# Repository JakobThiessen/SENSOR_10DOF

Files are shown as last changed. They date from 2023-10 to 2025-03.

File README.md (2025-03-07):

# SENSOR_10DOF

- ACC/Gyro	(BMI160/323)
- ACC/Mag	(LSM303AGR)
- T/P/RH	(BME280)

# Hardware

<p float="left">
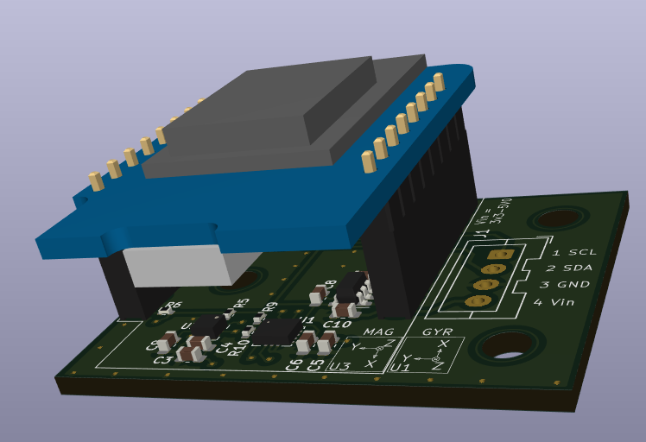
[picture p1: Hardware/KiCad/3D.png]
  
</p>

| Top side |Bottom side |
|---:|:---:|
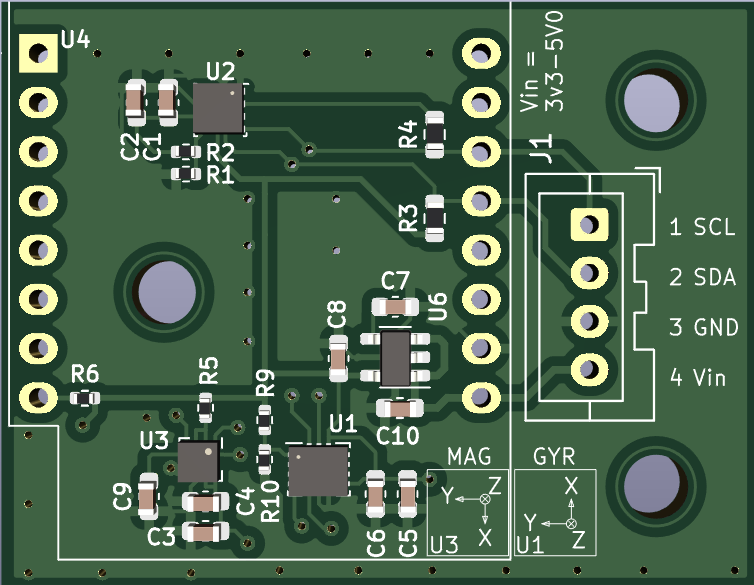
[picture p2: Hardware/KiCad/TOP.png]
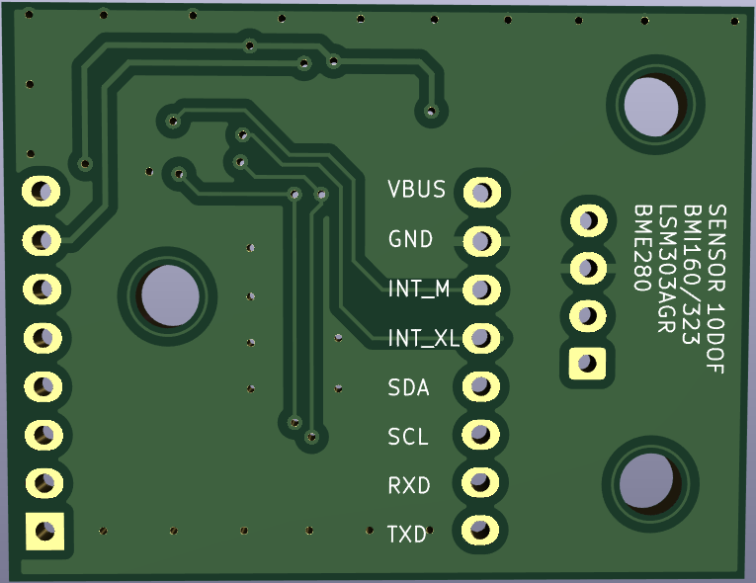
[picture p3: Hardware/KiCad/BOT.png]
|  |  |

<p float="left">
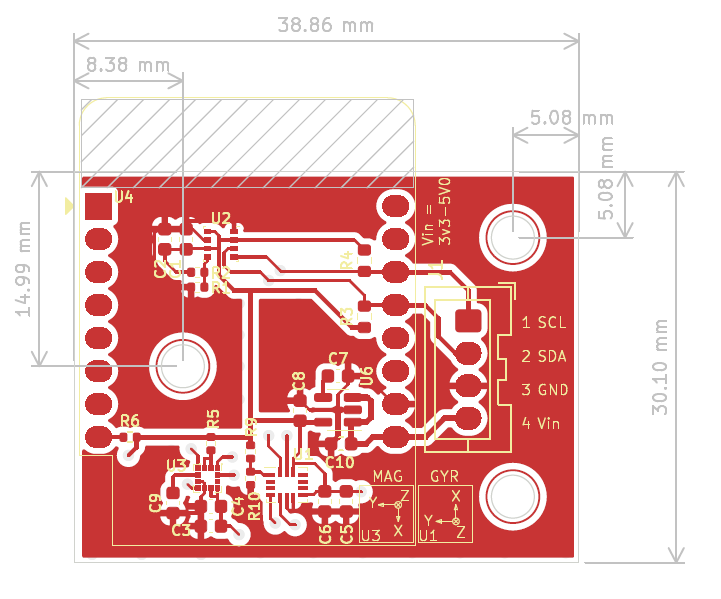
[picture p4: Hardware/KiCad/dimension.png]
  
</p>

| Values | Reference |
|---:|:---:|
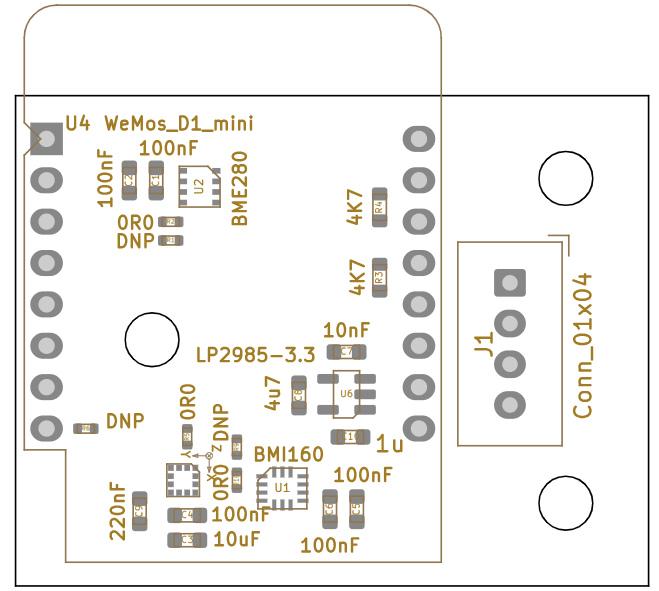
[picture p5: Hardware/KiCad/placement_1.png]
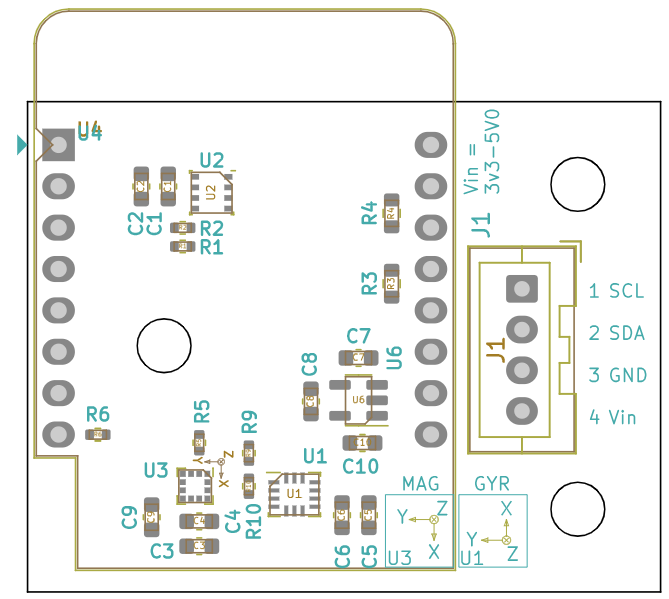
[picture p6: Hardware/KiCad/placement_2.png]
|  |  |

# Software

**BMI160:**
```diff
+ 0x68 --> SDO to GND (default)
# 0x69 --> SDO to VDDIO
```

**BMI323:**
```diff
+ 0x68 --> SDO to GND (default)
# 0x69 --> SDO to VDDIO
```

**BME280:**
```diff
+ 0x76 --> SDO to GND (default)
# 0x77 --> SDO to VDDIO
```

**LSM303AGR:**
```diff
+ 0x3A --> ACC (default)
+ 0x3C --> MAG (default)
```

## Driver

### lsm303agr

Standard C platform-independent drivers for MEMS motion and environmental sensors
- https://www.st.com/en/embedded-software/c-driver-mems.html
- https://github.com/STMicroelectronics/x-cube-mems1

Arduino/Grove
- https://github.com/Seeed-Studio/Grove_6Axis_Accelerometer_And_Compass/blob/master/examples/CompensatedCompass.ino

embedded/lsm303agr

``` c
/* USER CODE BEGIN PV */
static struct lsm303agr_dev Sensor;

/* USER CODE BEGIN 0 */
int8_t i2c_1_read(uint8_t dev_addr, uint8_t reg_addr, uint8_t *data, uint16_t len)
{
	int8_t result;

	result = HAL_I2C_Master_Transmit(&hi2c1, (uint16_t) dev_addr, &reg_addr, 1, 10);
	result += HAL_I2C_Master_Receive(&hi2c1, (uint16_t) dev_addr, data, len, 10);
	return result;
}

int8_t i2c_1_write(uint8_t dev_addr, uint8_t reg_addr, uint8_t *data, uint16_t len)
{
	int8_t result;
	uint8_t buffer[128];

	buffer[0] = reg_addr;
	memcpy(&buffer[1], data, len);

	result = HAL_I2C_Master_Transmit(&hi2c1, (uint16_t) dev_addr, buffer, len + 1, 100);
	return result;
}

void main(void)
{
	/* Hardware init*/
	
	........
	/*  */
	Sensor.dev_addr_mag = LSM303AGR_MAG_I2C_ADDRESS;
	Sensor.dev_addr_acc = LSM303AGR_ACC_I2C_ADDRESS;
	Sensor.read = i2c_1_read;
	Sensor.write = i2c_1_write;

	struct lsm303agr_mag_data magData;
	struct lsm303agr_acc_data accData;

	int8_t res = lsm303agr_mag_init(LSM303AGR_CONTINUOUS, &Sensor);
	res = lsm303agr_acc_init(LSM303AGR_ACC_NORMAL_MODE, &Sensor);

	...

	while (1)
	{
		int8_t rslt = 0;

		rslt = lsm303agr_mag_read_data(&magData, &Sensor);
		
		uint8_t data_ready_status = 0;
		lsm303agr_acc_get_DataReadyStatus(&data_ready_status, &Sensor);
		
		if (data_ready_status != 0)
		{
			lsm303agr_acc_read_data(&accData, &Sensor);
			rslt += lsm303agr_temp_read_data(&temperature, &Sensor);
		}
	}
}

```

### BMI160/323:

- https://github.com/boschsensortec/BMI160_driver
- https://github.com/boschsensortec/BMI323-Sensor-API

## Calibration of Magnetometer with Acc-Sensor

Application note: AN3192 Using LSM303DLH for a tilt compensated electronic compass

Masterarbeit
- https://reposit.haw-hamburg.de/bitstream/20.500.12738/8460/1/Masterarbeit_Tobias_Michaelsen.pdf

Lib von ST
- https://github.com/STMicroelectronics/x-cube-mems1

Eine Sammlung von Links zu dem Thema
- https://github.com/Seeed-Studio/Grove_6Axis_Accelerometer_And_Compass/blob/master/examples/CompensatedCompass.ino

- https://www.nxp.com/docs/en/application-note/AN4248.pdf
- https://www.nxp.com/docs/en/application-note/AN4249.pdf
- https://www.st.com/resource/en/design_tip/dt0058-computing-tilt-measurement-and-tiltcompensated-ecompass-stmicroelectronics.pdf
- https://www.bosch-sensortec.com/media/boschsensortec/downloads/datasheets/bst-bmm150-ds001.pdf

## Kalmanfilter
- https://www.cbcity.de/das-kalman-filter-einfach-erklaert-teil-1
- https://www.cbcity.de/das-kalman-filter-einfach-erklaert-teil-2
- https://www.cbcity.de/4d-kalman-filter-in-c
  
- https://www.halvorsen.blog/documents/automation/kalman_filter/LabVIEW%20Kalman%20Filter%20Examples.pdf

## Rotationsmatrix
- https://www.cbcity.de/tutorial-rotationsmatrix-und-quaternion-einfach-erklaert-in-din70000-zyx-konvention

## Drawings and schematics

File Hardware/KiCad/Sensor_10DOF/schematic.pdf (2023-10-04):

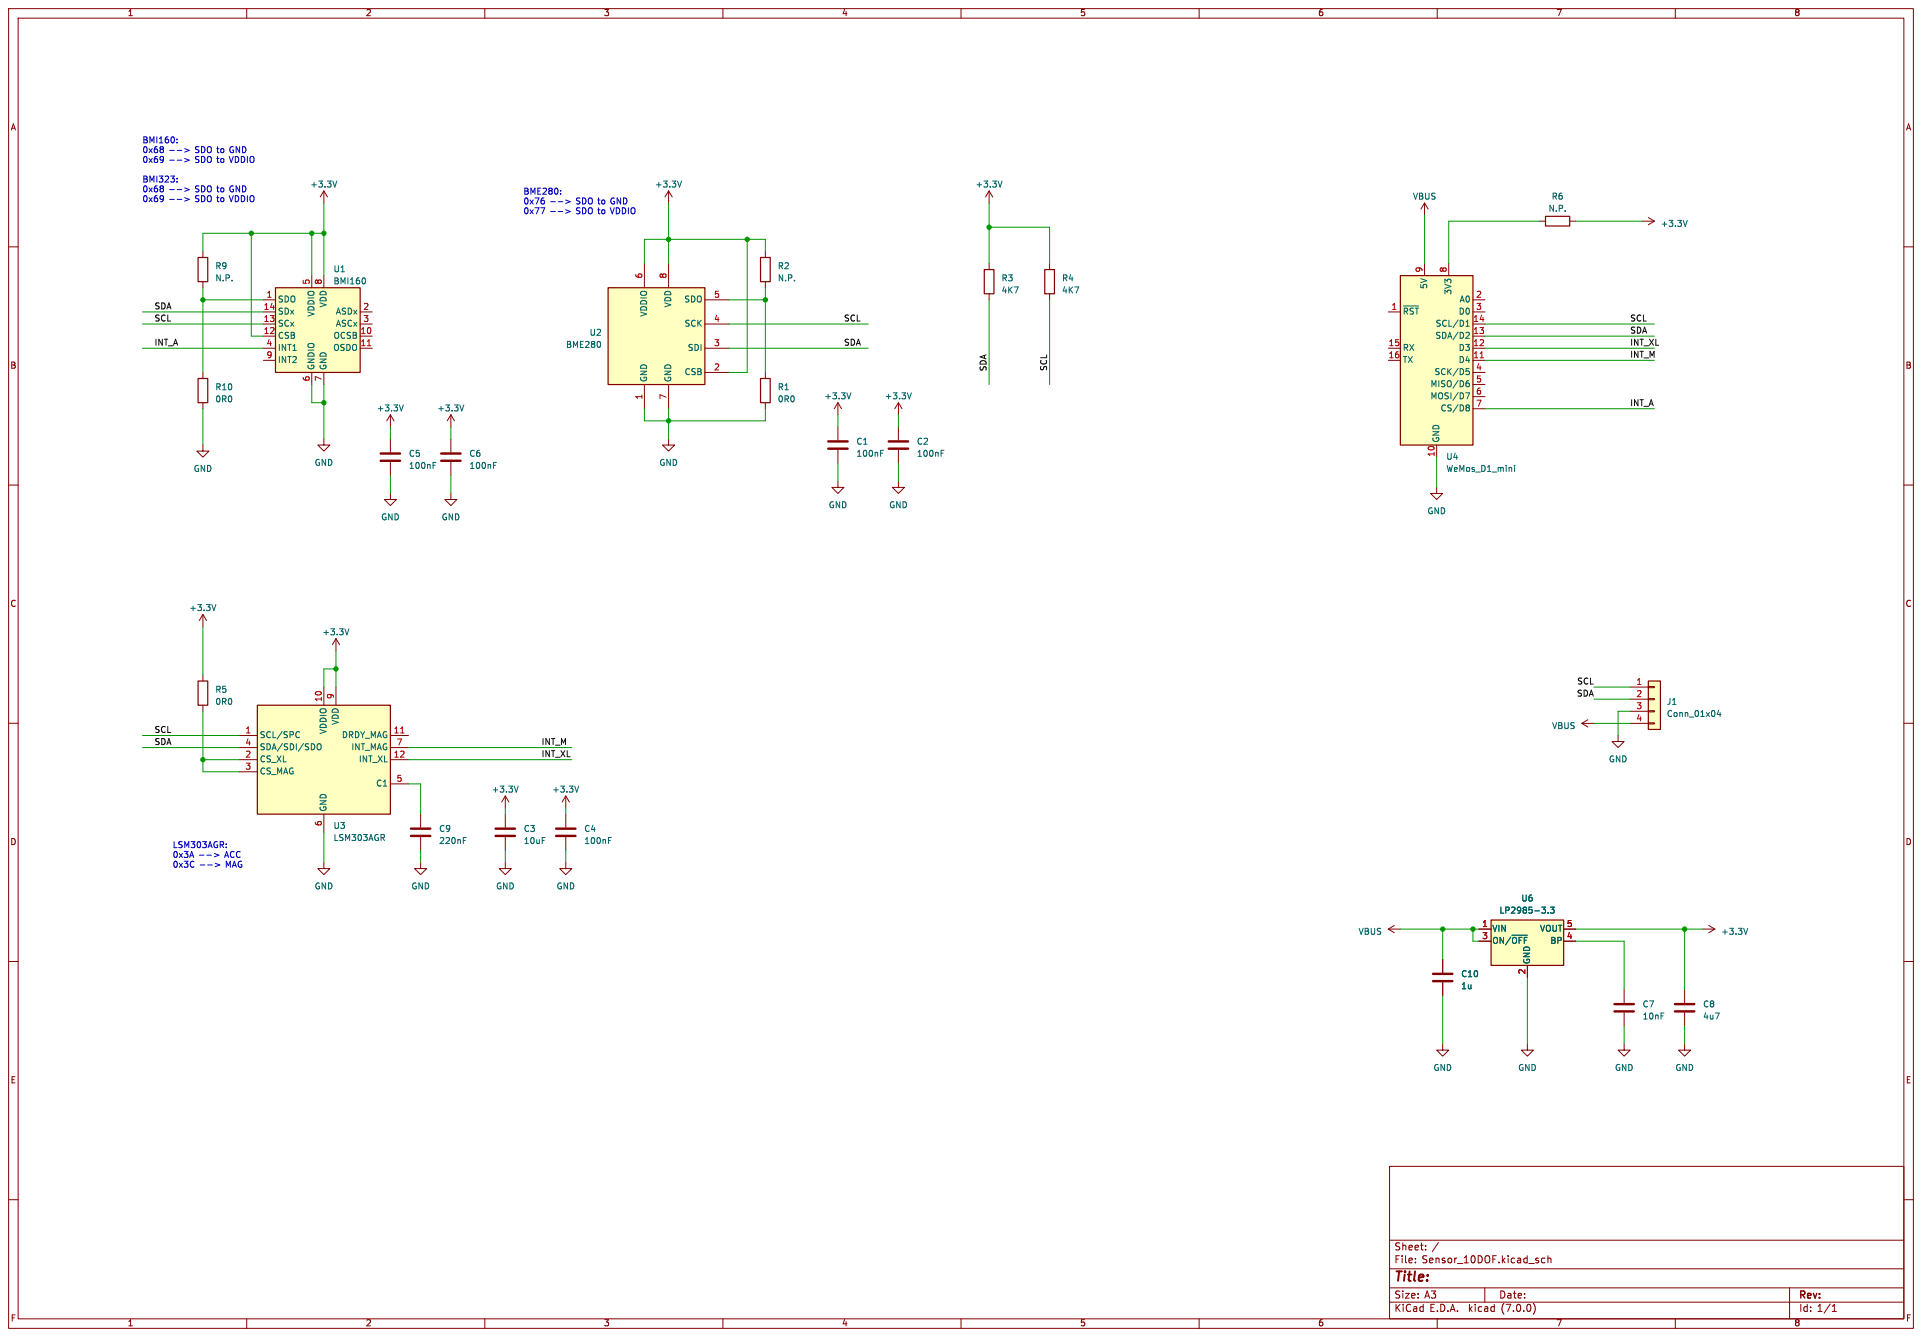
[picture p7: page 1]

1 CSB 2 SDI 3 SCK 4 SDO 5 VDDIO

2 ON/~{OFF} 3 BP 4 VOUT 5 U6

2 ON/~{OFF} 3 BP 4 VOUT 5 C10

Id: 1/1 Title: File: Sensor_10DOF.kicad_sch Sheet: /GND

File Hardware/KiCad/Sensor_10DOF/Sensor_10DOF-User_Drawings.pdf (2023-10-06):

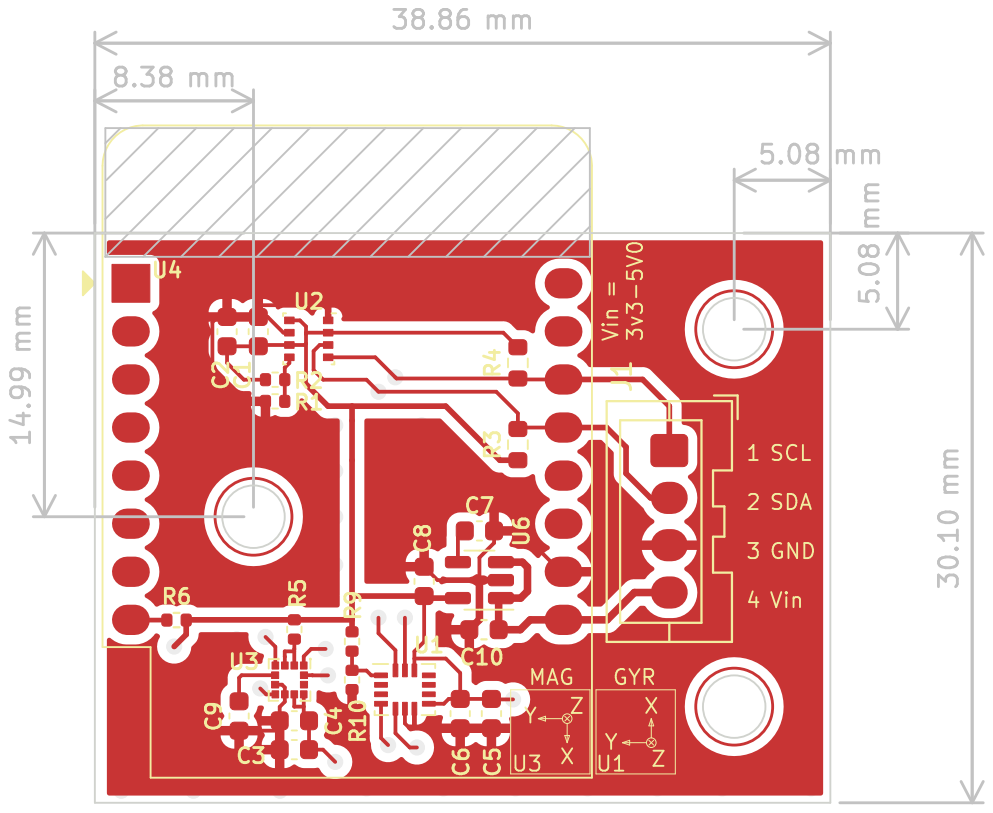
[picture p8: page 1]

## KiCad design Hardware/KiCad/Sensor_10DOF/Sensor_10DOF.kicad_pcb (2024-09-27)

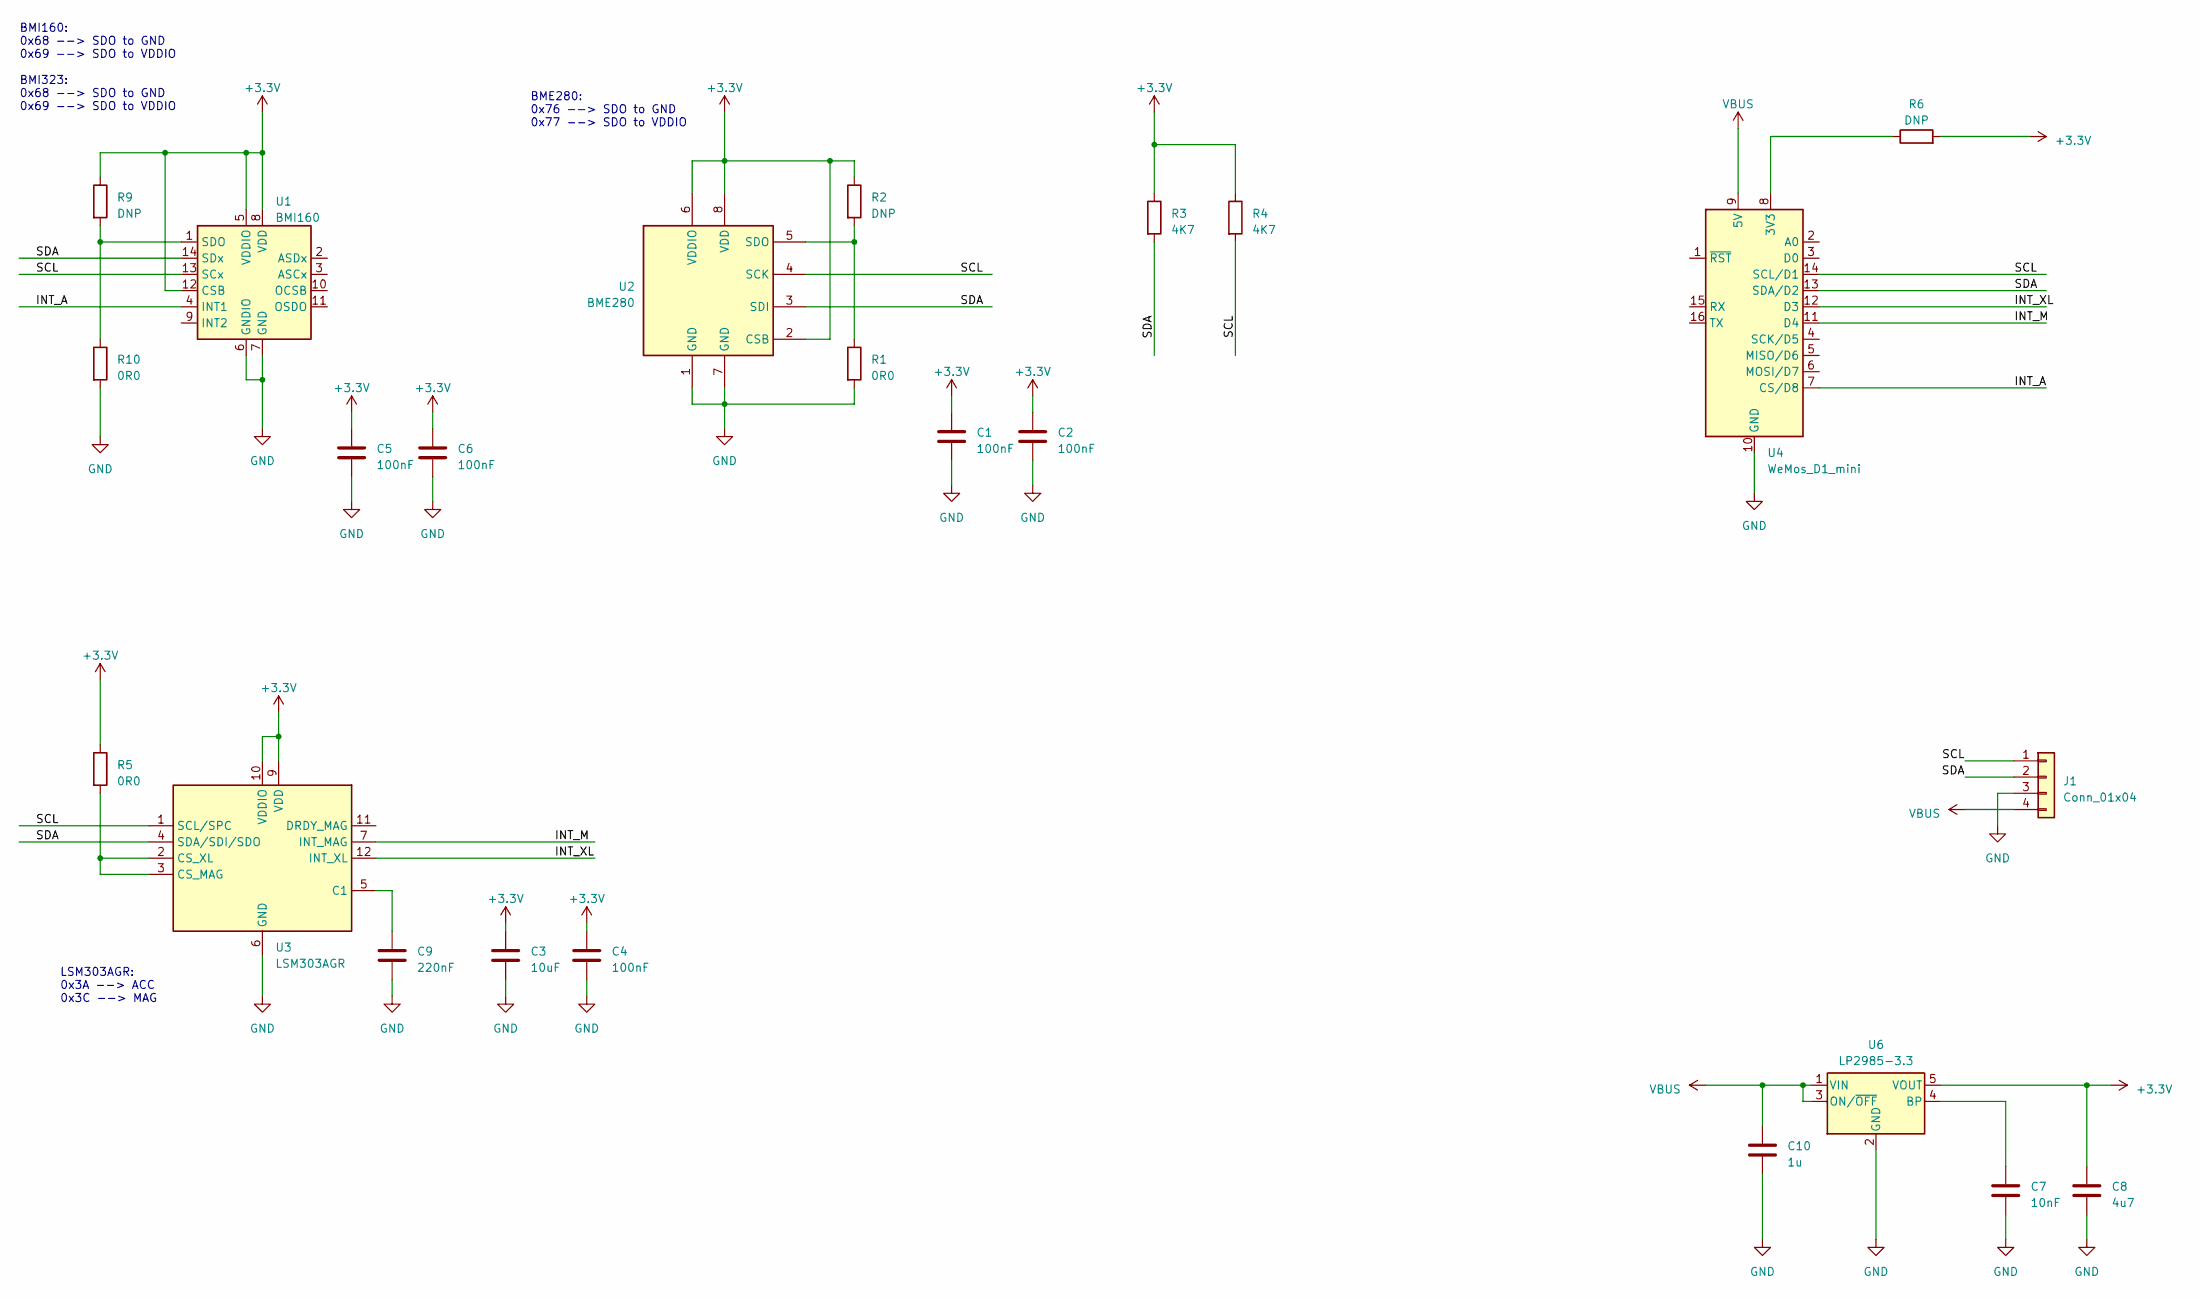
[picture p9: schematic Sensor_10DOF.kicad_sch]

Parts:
C1, C2, C4, C5, C6: 100nF; C_0603_1608Metric
C3: 10uF; C_0603_1608Metric
C7: 10nF; C_0603_1608Metric
C8: 4u7; C_0603_1608Metric
C9: 220nF; C_0603_1608Metric
C10: 1u; C_0603_1608Metric
J1: Conn_01x04; JST_XA_B04B-XASK-1_1x04_P2.50mm_Vertical
R1, R5, R10: 0R0; R_0402_1005Metric
R2, R6, R9: DNP; R_0402_1005Metric
R3, R4: 4K7; R_0603_1608Metric
U1: BMI160; Bosch_LGA-14_3x2.5mm_P0.5mm
U2: BME280; Bosch_LGA-8_2.5x2.5mm_P0.65mm_ClockwisePinNumbering
U3: LSM303AGR; LGA-12_2x2mm_P0.5mm
U4: WeMos_D1_mini; WEMOS_D1_mini_light
U6: LP2985-3.3; SOT-23-5

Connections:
+3.3V: C1.1, C2.1, C3.1, C4.1, C5.1, C6.1, C8.1, R2.1, R3.1, R4.1, R5.1, R6.2, R9.1, U1.5 (VDDIO), U1.8 (VDD), U1.12 (CSB), U2.2 (CSB), U2.6 (VDDIO), U2.8 (VDD), U3.9 (VDD), U3.10 (VDDIO), U6.5 (VOUT)
/INT_A: U1.4 (INT1), U4.7 (CS/D8)
/INT_M: U3.7 (INT_MAG), U4.11 (D4)
/INT_XL: U3.12 (INT_XL), U4.12 (D3)
/SCL: J1.1, R4.2, U1.13 (SCx), U2.4 (SCK), U3.1 (SCL/SPC), U4.14 (SCL/D1)
/SDA: J1.2, R3.2, U1.14 (SDx), U2.3 (SDI), U3.4 (SDA/SDI/SDO), U4.13 (SDA/D2)
GND: C1.2, C2.2, C3.2, C4.2, C5.2, C6.2, C7.2, C8.2, C9.2, C10.2, J1.3, R1.2, R10.2, U1.6 (GNDIO), U1.7 (GND), U2.1 (GND), U2.7 (GND), U3.6 (GND), U3.8 (GND), U4.10 (GND), U6.2 (GND)
unnamed: R9.2, R10.1, U1.1 (SDO)
unnamed: R1.1, R2.2, U2.5 (SDO)
unnamed: C9.1, U3.5 (C1)
unnamed: R5.2, U3.2 (CS_XL), U3.3 (CS_MAG)
unnamed: R6.1, U4.8 (3V3)
unnamed: C7.1, U6.4 (BP)
VBUS: C10.1, J1.4, U4.9 (5V), U6.1 (VIN), U6.3 (ON/~OFF)

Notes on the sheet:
BME280: 0x76 --> SDO to GND 0x77 --> SDO to VDDIO
BMI160: 0x68 --> SDO to GND 0x69 --> SDO to VDDIO BMI323: 0x68 --> SDO to GND 0x69 --> SDO to VDDIO
LSM303AGR: 0x3A --> ACC 0x3C --> MAG

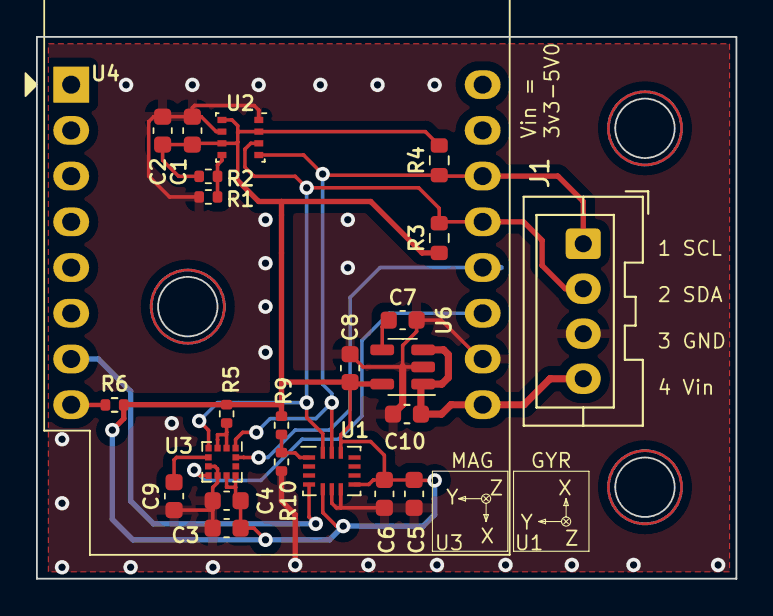
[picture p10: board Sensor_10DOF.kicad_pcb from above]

Board: 2 copper layers, 38.9 x 30.1 mm, 24 parts (0 on the bottom side), 14 nets.

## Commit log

2023-09-30 fast fertig. Pinbelegung prüfen
    [Sensor_10DOF.kicad_pcb, Sensor_10DOF.kicad_sch]
2023-09-30 bild hinzugefügt PCB -> text geändert
    [Sensor_10DOF.kicad_pcb]
2023-09-30 Rename --> Sensor_10DOF.pdf pdf to schematic.pdf
    [Sensor_10DOF.kicad_sch]
2023-10-04 version 1.0 - release Gerberdaten erzeugt
    [Sensor_10DOF.kicad_pcb, Sensor_10DOF.kicad_sch]
2023-10-06 fix gerber
    [Sensor_10DOF.kicad_pcb]
2023-10-07 bestückungsplan erstellt
    [Sensor_10DOF.kicad_pcb, Sensor_10DOF.kicad_sch]
2024-09-27 add .gitignore
    [Sensor_10DOF.kicad_pcb]
2025-03-07 add embedded folder
    [Sensor_10DOF.kicad_sch]
